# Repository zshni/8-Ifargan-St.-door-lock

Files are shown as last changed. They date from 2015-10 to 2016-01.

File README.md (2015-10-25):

מנעול מגנטי לדלת הכניסה לבניין
===========================
<br>המנעול נרכש באתר
<br>www.banggood.com
<br>ראה
<br>http://www.banggood.com/280kg-Single-Magnetic-Door-Lock-XJL-SK280-Electronic-Door-Lock-p-83624.html
<br>את המעגל החשמלי תכננתי ובניתי. הסכימה מצורפת בזה
<br><br>המעגל החשמלי מחולק לשתי תיבות: אחת מורכבת על המנעול ונקראת
<br>Buzzer and Saturday switch box
<br>השניה מורכבת בארון בזק בלובי ונקראת 
<br>Contactors box
<br><br>החיבור בין שתי הקופסאות מתבצע באמצעות שרשור של ארבעה כבלים:
<br>מקטע 1: צמה שטוחה מהמנעול העליון אל איזור המנעול הישן בדלת.
<br>מקטע 2: כבל לבן 4 גידי קצר מאיזור המנעול הישן בדלת אל פנל הכניסה.
<br>מקטע 3: כבל לבן רב גידי מפנל הכניסה אל ארון בזק
<br>מקטע 4: כבל לבן 4 גידי קצר מהכבל הרב גידי אל ה 
<br>contactors box
<br>מקטעים 3 ו- 4 היו קיימים בחיווט של הבנין ולא ניתן להחליפם
<br>

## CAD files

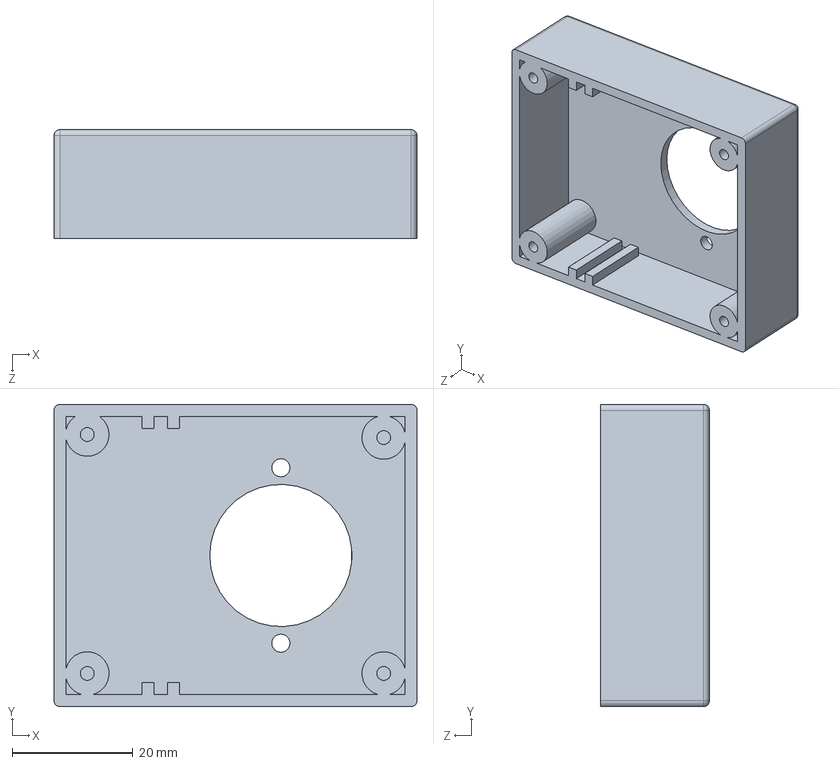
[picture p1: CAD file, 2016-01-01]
PIR sensor box.SLDPRT
60.0 x 50.0 x 18.0 mm

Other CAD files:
PIR sensor box.STL

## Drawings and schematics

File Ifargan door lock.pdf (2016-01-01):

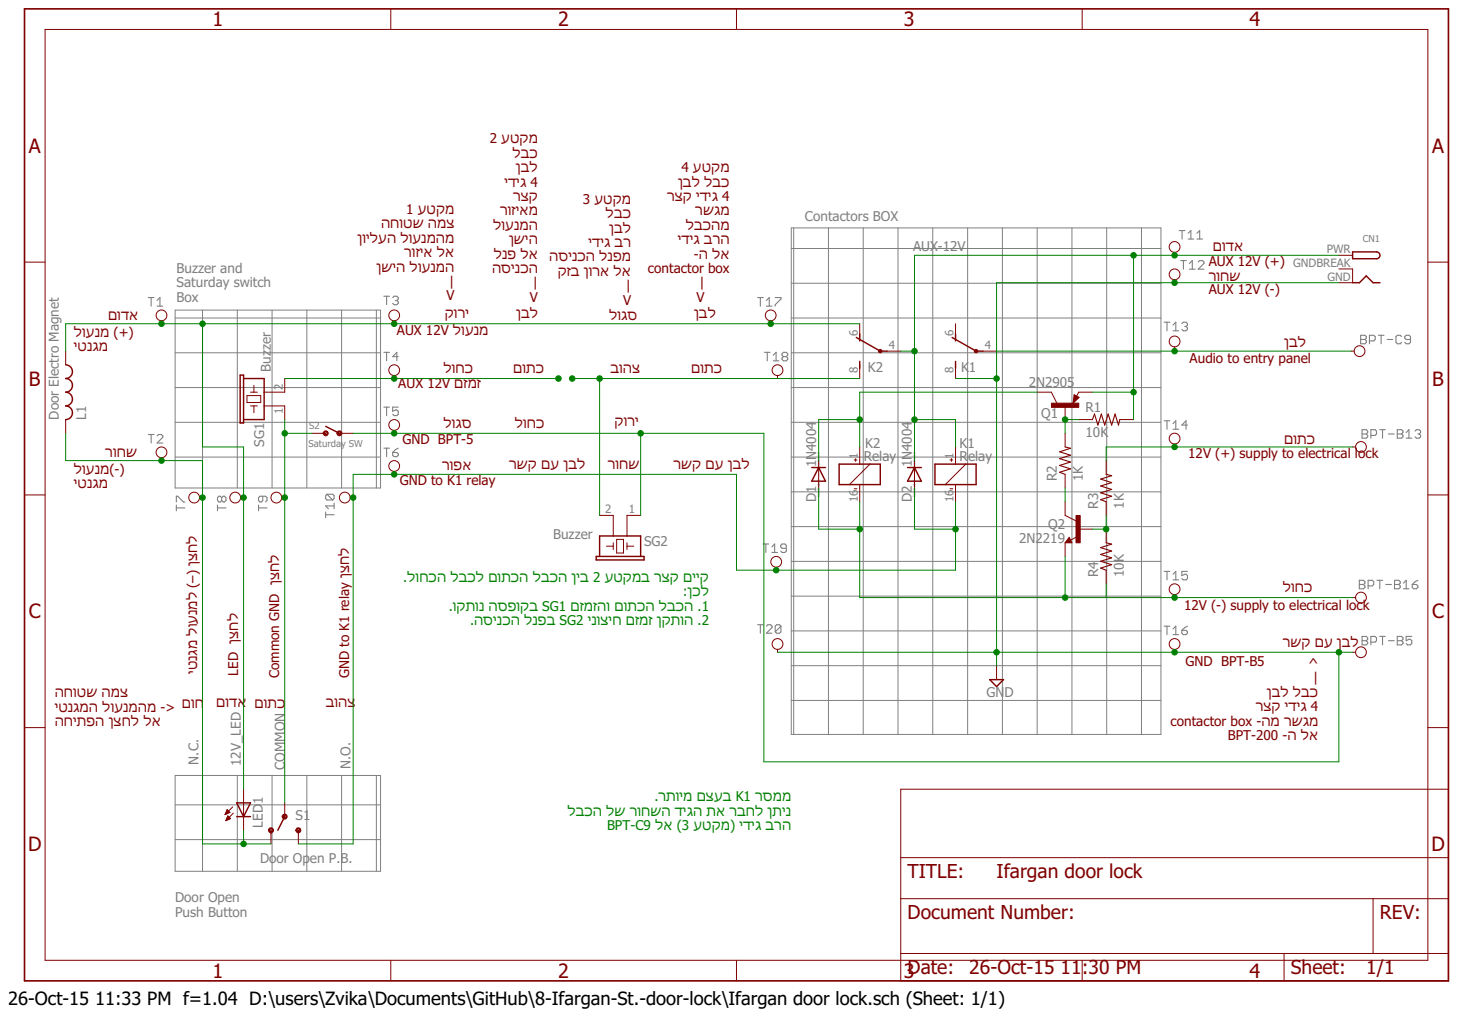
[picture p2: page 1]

AUX 12V (-) Audio to entry panel כתום

כחול ירוק AUX 12V מנעול צהוב כתום כתום

K2 | | 2N2905

GND BPT-5 אפור | שחור לבן עם קשר ירוק כחול | לבן עם קשר

12V (+) supply to electrical lock

Com ןצחל LED ןצחל )– ( ל וע נמל יט נגמ

mon GND ןצחל GND to K1 relay ןצחל

קיים קצר במקטע 2 בין הכבל הכתום לכבל הכחול.

.1 הכבל הכתום והזמזם 1SG בקופסה נותקו.
.2 הותקן זמזם חיצוני 2SG בפנל הכניסה.

12V (-) supply to electrical lock

צהוב כתום אדום חום

מגשר מה- box contactor

ניתן לחבר את הגיד השחור של הכבל

הרב גידי (מקטע 3) אל 9C-BPT

TITLE: Ifargan door lock

Document Number: | REV:

26-Oct-15 11:33 PM f=1.04 D:\users\Zvika\Documents\GitHub\8-Ifargan-St.-door-lock\Ifargan door lock.sch (Sheet: 1/1)

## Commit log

2015-10-25 base design
    [Ifargan door lock.sch]
2016-01-01 Final working design
    Installed on the front door at 01-01-2015
    [Ifargan door lock with PIR.sch, PIR sensor box.SLDPRT, PIR sensor box.STL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]
2016-01-01 removed
    old design. without PIR sensor
    [Ifargan door lock.sch]
2016-01-03 Schematics changes
    R1 changed to 1K.
    C1 10uF capacitor added in parallel to the buzzer
    [buzzer 12v limiter.sch]
